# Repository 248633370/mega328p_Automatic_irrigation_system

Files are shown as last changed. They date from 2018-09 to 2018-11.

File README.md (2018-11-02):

# mega328p_Automatic_irrigation_system
Yet another automatic irrigation system

System based on atmega328p (Arduino can be used - overkill, but was designed for "on hands" materials).
It measure humidity about each 12 hours by two-needle sensor.

Device powered from ATX PSU +5V standby, and manage PS_ON by optocoupler for start PSU and use +12V through relay for drive water pump.
Device irrigate 10 seconds(hardcoded), after that measure humidity one more time to determine need iriigate once more.

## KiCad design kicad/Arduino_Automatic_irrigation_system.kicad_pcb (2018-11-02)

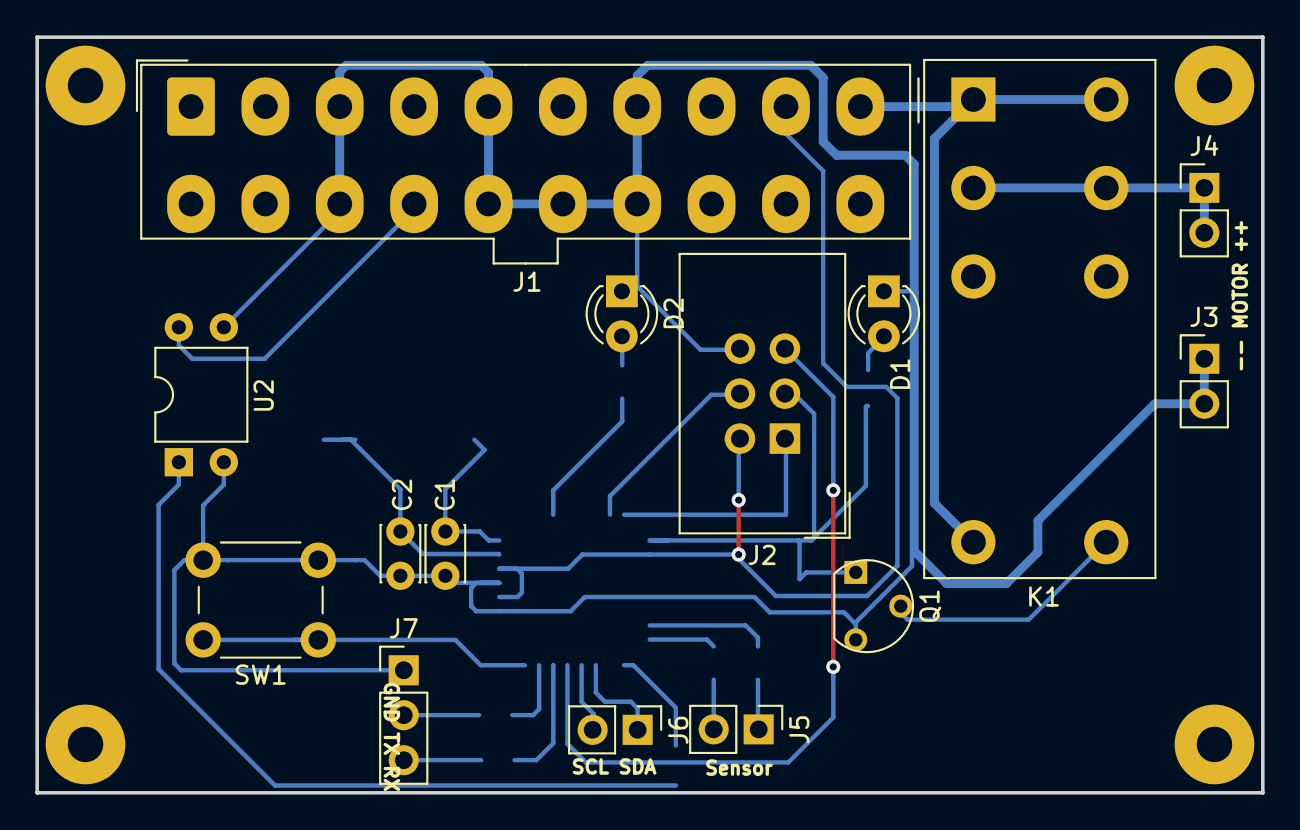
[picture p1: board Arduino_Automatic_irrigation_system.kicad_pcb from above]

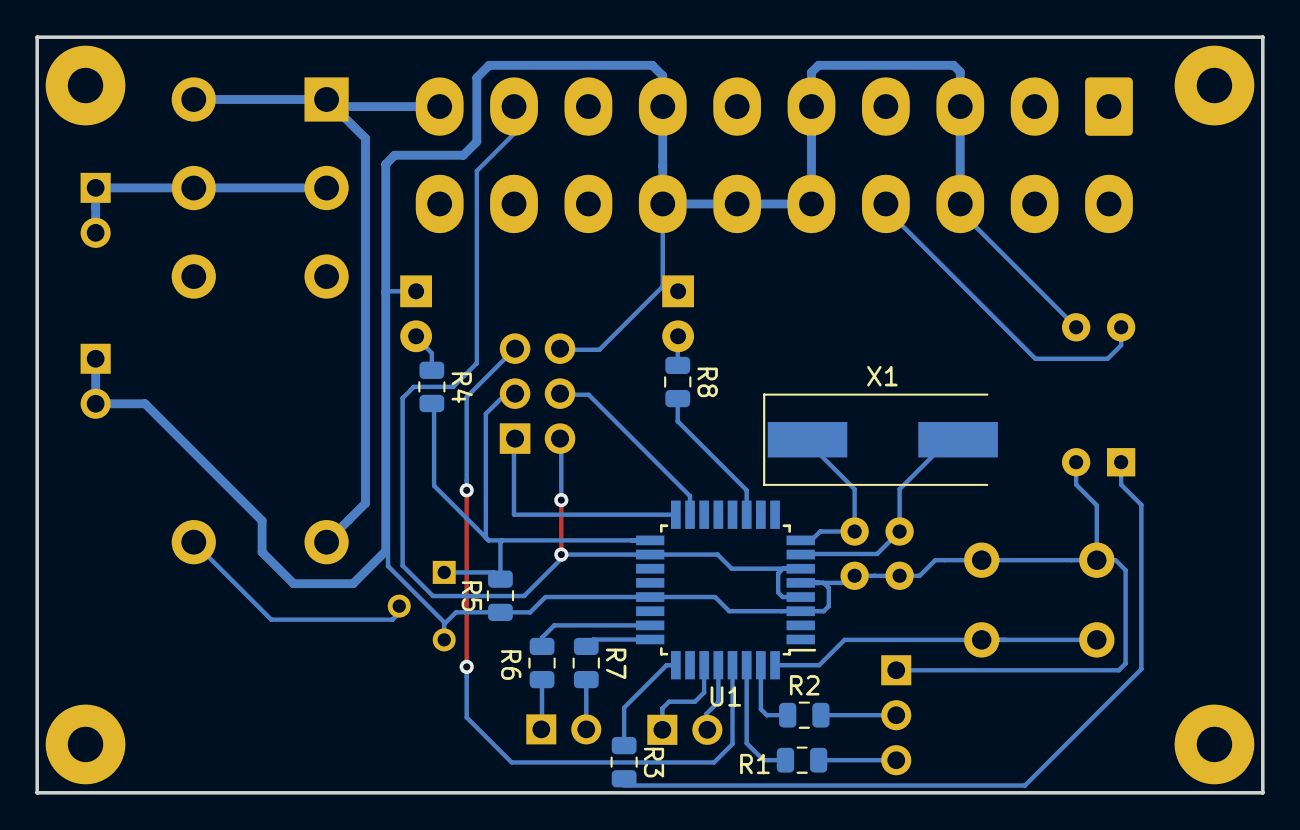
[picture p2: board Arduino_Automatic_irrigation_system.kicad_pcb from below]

Board: 2 copper layers, 69.2 x 42.7 mm, 25 parts (10 on the bottom side), 28 nets.

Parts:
C1, C2: 22p; C_Disc_D3.0mm_W2.0mm_P2.50mm
D1, D2: LED; LED_D3.0mm
J1: Conn_02x10_Top_Bottom; Molex_Mini-Fit_Jr_5566-20A_2x10_P4.20mm_Vertical
J2: AVR-ISP-6; IDC-Header_2x03_P2.54mm_Vertical
J3: Motor-; PinHeader_1x02_P2.54mm_Vertical
J4: Motor+; PinHeader_1x02_P2.54mm_Vertical
J5: Sensor; PinHeader_1x02_P2.54mm_Vertical
J6: sclI2Csda; PinHeader_1x02_P2.54mm_Vertical
J7: GND TX RX; PinHeader_1x03_P2.54mm_Vertical
K1: Fujitsu_FTR-F1C; Relay_DPDT_Fujitsu_FTR-F1C
Q1: BSS295; TO-92_wider_pitch
R1, R2, R4, R8: 1k; R_0805_2012Metric
R3: 100; R_0805_2012Metric
R5, R6, R7: 100k; R_0805_2012Metric
SW1: SW_Push; SW_PUSH_6mm_H9.5mm
U1: ATmega328P-AU; TQFP-32_7x7mm_P0.8mm
U2: SFH617A-4; DIP-4_W7.62mm
X1: 16MHz; Crystal_SMD_HC49-SD

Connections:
+5V: J1.9, J2.2, U1.4, U1.6, U1.18
+12V: J1.10, K1.1, K1.4, K1.8
ADC0: R6.1, U1.23
ADC1: R7.1, U1.24
GND: C1.2, C2.2, D1.1, D2.1, J1.3, J1.5, J1.7, J1.13, J1.15, J1.16, J1.17, J2.6, J3.1, J3.2, J7.1, Q1.3, R5.1, SW1.2, U1.3, U1.5, U1.21, U2.2, U2.3
MISO: J2.1, U1.16
MOSI: J2.4, U1.15
unnamed: C1.1, U1.8, X1.1
unnamed: C2.1, U1.7, X1.2
unnamed: D1.2, R4.1
unnamed: D2.2, R8.1
unnamed: J1.14, U2.4
unnamed: J4.1, J4.2, K1.2, K1.7
unnamed: J5.1, R6.2
unnamed: J5.2, R7.2
unnamed: K1.5, Q1.2
unnamed: R1.1, U1.30
unnamed: R2.1, U1.31
unnamed: R3.1, U1.25
unnamed: R3.2, U2.1
unnamed: R8.2, U1.11
unnamed: SW1.1, U1.32
RST: J2.5, U1.29
RX: J7.3, R1.2
SCK: J2.3, Q1.1, R4.2, R5.2, U1.17
SCL: J6.2, U1.28
SDA: J6.1, U1.27
TX: J7.2, R2.2

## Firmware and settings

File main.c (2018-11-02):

/*
 * main.c
 *
 *  Created on: 16.08.2018
 *      Author: Anton Nechaev
 *      Yet another automatic irrigation system
 * DDRxn=0 PORTxn=0 – HI-Z
 * DDRxn=0 PORTxn=1 – PullUp
 * DDRxn=1 PORTxn=0 – OutLow
 * DDRxn=1 PORTxn=1 – OutHi
 *
 */

#include <avr/io.h>
#include <avr/interrupt.h>
#include <util/delay.h>
#include <util/twi.h>
#include <stdio.h>

#ifndef F_CPU
	#define F_PCU 16000000UL
#endif
/*
 * Set FUSE on external clock source from quartz 16 MHz
 */
#define DEBUG true //UART and/or i2c debug output
#ifdef DEBUG
	#include "uart.h"
#endif


#define SENSOR_PORT PORTC
#define SENSOR_REGISTER DDRC
#define SENSOR_PIN0 PC0
#define SENSOR_PIN1 PC1
#define ATX_PIN PC2
#define BUTTON_PORT PORTD
#define BUTTON_REGISTER DDRD
#define BUTTON_PIN PD2
#define MOTOR_REGISTER DDRB
#define MOTOR_PORT PORTB
#define HERATBEAT_PIN PB3
#define MOTOR_PIN PB5


volatile uint32_t timer1;
struct {
	uint8_t forward;
	uint8_t reverse;
	uint8_t calculated;
}humidity;
volatile signed char inc = 1;//heartbeat increment

volatile const uint32_t half_day = 10676; // ~12 hours

void port_config(void)
{
	SENSOR_REGISTER |= (1<<ATX_PIN); //set ATX_PIN to out
	//SENSOR_PORT |= (1<<SENSOR_PIN0)|(1<<SENSOR_PIN1);
	BUTTON_PORT |= (1<<BUTTON_PIN); // enable PulUP
	EIMSK |= (1<<INT0); // Interrupt for INT0

	TCCR1B |= (1<<CS12)|(1<<CS10);//set clk/1024 prescaler, period 64us timer1
	TIMSK1 |= (1<<ICIE1)|(1<<TOIE1);// enable timer1 interrupt

	ADMUX |= (1<<ADLAR) // set left adjusted result 10-bit ADC
			|(1<<REFS0);// set ref as AVCC
	ADCSRA |= (1<<ADEN)|(1<<ADSC) // enable ADC
		|(1<<ADPS2)|(1<<ADPS1)|(1<<ADPS0); // Prescaler /128

	MOTOR_REGISTER |= (1<<MOTOR_PIN)|(1<<HERATBEAT_PIN);// set ports as out
	// set Fast PWM
	TCCR2A |= (1<<COM2A1)|(1<<COM2A0)
			|(1<<WGM21)|(1<<WGM20);
	//COM2A[1..0] b11 - Set OC2A on Compare Match, clear OC2A at BOTTOM,    (inverting mode)
	//WGM2[2..0] b011 - mode 3 Fast PWM top - 0xFF
	TCCR2B |= (1<<CS22)|(1<<CS21);//|(1<<CS20);
	// b111 - /1024 prescaler
	TIMSK2 |= (1<<TOIE2);
}


uint8_t check_humidity(uint8_t direction) // Check humidity in both direction to prevent electric oxidation
{
	if (direction == 0)
	{
		SENSOR_PORT |= (1<<SENSOR_PIN1);
	} else {
		SENSOR_PORT |= (1<<SENSOR_PIN0);
		ADMUX |= (1<<MUX0); //connect PIN1 to ADC
	}
	ADCSRA &= ~(1<<ADIF); //Start ADC
	ADCSRA |= (1<<ADSC);
	while(ADCSRA & (1<<ADSC)); // wait ADC
	SENSOR_PORT &= ~((1<<SENSOR_PIN0)|(1<<SENSOR_PIN1));
	ADMUX &= ~(1<<MUX0);
	return ADCH; // left adjusted, need only highest bits
}

void irrigate(int ms_time) // enable water pump in ms
{
	MOTOR_PORT |= (1<<MOTOR_PIN);
	int i;
	for (i = 0; i < (ms_time / 10); i++) {
		_delay_ms(10);
	}
	MOTOR_PORT &= ~(1<<MOTOR_PIN);
}

ISR(TIMER1_OVF_vect)
{
	timer1++;
	#ifdef DEBUG
		printf("Timer1: %lu\n", timer1);
	#endif
}

ISR(TIMER2_OVF_vect)
{
	OCR2A = OCR2A + inc;
	if (OCR2A == 254 || OCR2A == 0)
	{
		inc = inc * -1;
		//PORTB ^= (1<<PB5);
	}
}

ISR(INT0_vect)
{
	timer1 = half_day - 1;
	#ifdef DEBUG
		printf("Button pressed!\n");
		printf("Timer1: %lu\n", timer1);
	#endif

}

int main(void)
{
	port_config();
	uart_config();
    stdout = &uart_output;
    stdin  = &uart_input;
	sei();

	#ifdef DEBUG
		printf("Auto irrigation system is started\n");
	#endif

	while(1)
	{
		if (timer1 >= half_day)
		{
			timer1 = 0;
			humidity.forward = check_humidity(0);
			_delay_ms(100); //0.1 sec delay for discharge
			humidity.reverse = check_humidity(1); //checking with reversed polarity for prevent electrodes degradation
			humidity.calculated = (humidity.forward + humidity.reverse) / 2;
			#ifdef DEBUG
				printf("Humidity:%d %d %d\n", humidity.forward, humidity.reverse, humidity.calculated);
			#endif
			if (humidity.calculated < 128)
			{
				#ifdef DEBUG
					printf("Start ATX(1 sec)\n");
				#endif
				SENSOR_PORT |= (1<<ATX_PIN);
				_delay_ms(1000); //delay for 1 second during ATX start
				#ifdef DEBUG
					printf("irrigation 10 sec\n");
				#endif
				irrigate(10000);
				timer1 = half_day - 1;
			} else {
				SENSOR_PORT &= ~(1<<ATX_PIN);
			}
		}
	}
}

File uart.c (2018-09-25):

#include <avr/io.h>
#include <stdio.h>

#ifndef F_CPU
#define F_CPU 16000000UL
#endif

#ifndef BAUD
#define BAUD 9600
#endif
#include <util/setbaud.h>

/* http://www.cs.mun.ca/~rod/Winter2007/4723/notes/serial/serial.html */

void uart_config(void) {
    UBRR0H = UBRRH_VALUE;
    UBRR0L = UBRRL_VALUE;

#if USE_2X
    UCSR0A |= _BV(U2X0);
#else
    UCSR0A &= ~(_BV(U2X0));
#endif

    UCSR0C = _BV(UCSZ01) | _BV(UCSZ00); /* 8-bit data */
    UCSR0B = _BV(RXEN0) | _BV(TXEN0);   /* Enable RX and TX */
}

void uart_putchar(char c, FILE *stream) {
    if (c == '\n') {
        uart_putchar('\r', stream);
    }
    loop_until_bit_is_set(UCSR0A, UDRE0);
    UDR0 = c;
}

char uart_getchar(FILE *stream) {
    loop_until_bit_is_set(UCSR0A, RXC0);
    return UDR0;
}

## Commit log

2018-09-25 Irrigateion system wit UART and i2c debug
2018-10-29 Heartbeat, UART, i2c
2018-10-29 Working. UART and heartbeat
2018-11-02 kicad project
    [Arduino_Automatic_irrigation_system.kicad_pcb, Arduino_Automatic_irrigation_system.sch]
